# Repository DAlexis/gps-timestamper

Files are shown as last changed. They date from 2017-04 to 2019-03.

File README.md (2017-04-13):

GPS timestamper project
=======================

Open-source device based on STM32 that provides precision time stamps
of trigger signal connected to input. It use GPS PPS signal to provide
~1uS precision time mesurment. Also it makes self-calibration by PPS
every second.

Device may be used to synchronize any signals and data streams without
wired or wireless connection i.e. in geophysical researches, lightning 
detection networks, seismology and others

Currently project in protortype state and under development. Primary
function (precision timestamping) works correctly.

# Build
To build firmware you may have installed `arm-gcc` toolchain on your
linux system. If you do not need unit tests, simply comment out
corresponding line in root CMakeLists.txt (to build tests `gtest` should
be installed on your system)

Run `build.sh` and thats all. To flash MCU, connect ST-Link device to
PC and then run `flash.sh`.

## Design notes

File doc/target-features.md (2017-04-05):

Планируемый функционал прибора
=====

# Основные функции
- Много входных каналов, исключающих одновременную работу. 
(Может возникнуть трудность при неодновременном переключении)
- ЦАП устанавливает потог срабатывания
- Выход PPS
- Передача времени после каждого PPS в компьютер (можно сделать опционально через один из каналов)
- Интерфейс для тэга следующего события. Два режима - вход и выход. Выход
непрерывно повторяет тэг, вход его принимает и устанавливает взамен случайно сгенерированного
Установка тэга может быть по USB. Сгенерированные и внешние тэги различаются специальным битом

# Дополнительные функции
- Светодиод и опционально - зуммер при наличии синхросигнала, управляемый программно
(не напрямую от сигнала)

# Способы тестирования
- Соединить выход PPS со входом канала. Должно быть ровное время.
- Подаваить импульсы от стабильного генератора

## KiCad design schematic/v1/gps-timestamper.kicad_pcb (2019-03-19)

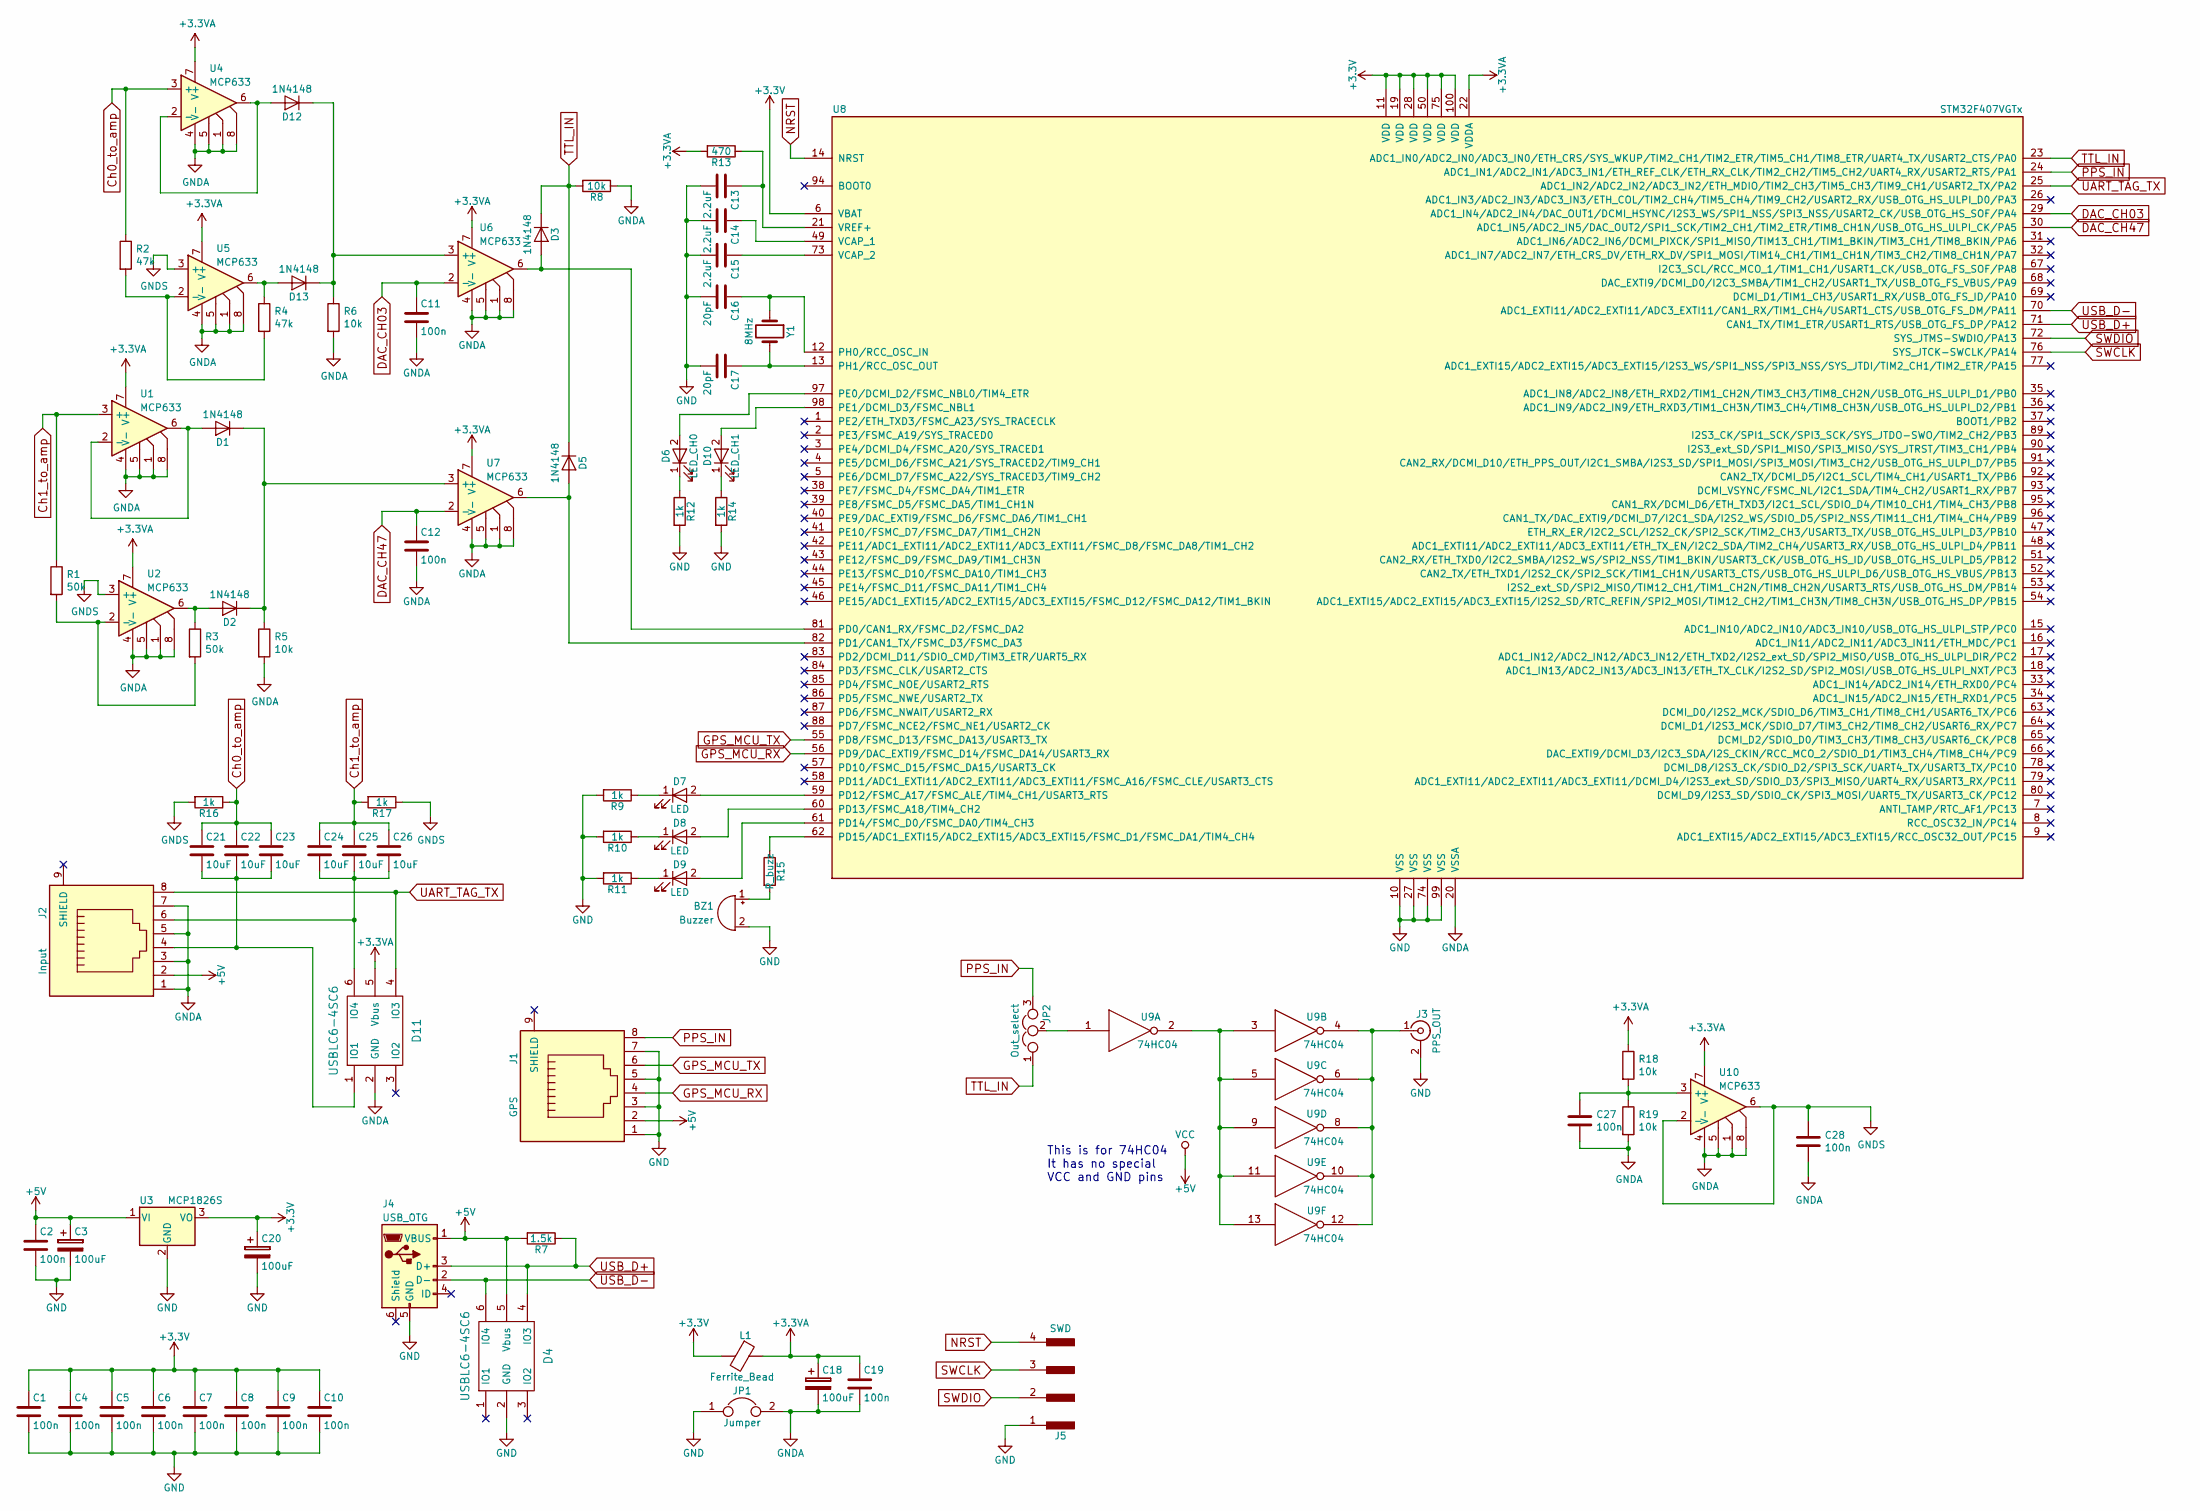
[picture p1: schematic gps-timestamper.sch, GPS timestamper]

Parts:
BZ1: Buzzer; Buzzer_12x9.5RM7.6
C1, C2, C4, C5, C6, C7, C8, C9, C10, C11, C12, C19, C27, C28: 100n; C_0805
C3, C18, C20: 100uF; CP_Tantalum_Case-B_EIA-3528-21_Wave
C13, C14, C15: 2.2uF; C_0805
C16, C17: 20pF; C_0805
C21, C22, C23, C24, C25, C26: 10uF; C_0805
D1, D2, D3, D5, D12, D13: 1N4148; D_SOD-323
D4, D11: USBLC6-4SC6; SOT-23-6
D6: LED_CH0; LED_0805
D7, D8, D9: LED; LED_0805
D10: LED_CH1; LED_0805
J1: GPS; RJ45_8
J2: Input; RJ45_8
J3: PPS_OUT; SMA_THT_Jack_Straight
J4: USB_OTG; USB_Micro-B
J5: SWD; Pin_Header_Straight_1x04_Pitch2.54mm
JP1: Jumper; GS2
JP2: Out_select; Pin_Header_Straight_1x03_Pitch2.54mm
L1: Ferrite_Bead; R_0805
R1, R3: 50k; R_0805
R2, R4: 47k; R_0805
R5, R6, R8, R18, R19: 10k; R_0805
R7: 1.5k; R_0805
R9, R10, R11, R12, R14, R16, R17: 1k; R_0805
R13: 470; R_0805
R15: R_buzz; R_0805
U1, U2, U4, U5, U6, U7, U10: MCP633; SOIC-8-N
U3: MCP1826S; SOT-223-3_TabPin2
U8: STM32F407VGTx; LQFP-100_14x14mm_Pitch0.5mm
U9: 74HC04; SOIC-14_N
Y1: 8MHz; Crystal_HC49-U_Vertical

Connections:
+3.3VA: C18.1, C19.1, D11.5 (Vbus), L1.1, R13.2, R18.1, U1.7 (V+), U2.7 (V+), U4.7 (V+), U5.7 (V+), U6.7 (V+), U7.7 (V+), U8.22 (VDDA), U10.7 (V+)
+3V3: C1.1, C4.1, C5.1, C6.1, C7.1, C8.1, C9.1, C10.1, C20.1, L1.2, U3.3 (VO), U8.6 (VBAT), U8.11 (VDD), U8.19 (VDD), U8.28 (VDD), U8.50 (VDD), U8.75 (VDD), U8.100 (VDD)
+5V: C2.1, C3.1, D4.5 (Vbus), J1.2, J2.2, J4.1 (VBUS), R7.2, U3.1 (VI), U9.14 (VCC)
Ch0_to_amp: C21.1, C22.1, C23.1, R2.1, R16.1, U4.3 (+)
Ch1_to_amp: C24.1, C25.1, C26.1, R1.1, R17.2, U1.3 (+)
DAC_CH03: C11.1, U6.2 (-), U8.29 (ADC1_IN4/ADC2_IN4/DAC_OUT1/DCMI_HSYNC/I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)
DAC_CH47: C12.1, U7.2 (-), U8.30 (ADC1_IN5/ADC2_IN5/DAC_OUT2/SPI1_SCK/TIM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)
GND: BZ1.2 (+), C1.2, C2.2, C3.2, C4.2, C5.2, C6.2, C7.2, C8.2, C9.2, C10.2, C13.2, C14.2, C15.2, C16.2, C17.2, C20.2, D4.2 (GND), J1.1, J1.3, J1.5, J1.7, J3.2 (Ext), J4.5 (GND), J5.1, JP1.1, R9.2, R10.2, R11.2, R12.2, R14.2, U3.2 (GND), U8.10 (VSS), U8.27 (VSS), U8.74 (VSS), U8.99 (VSS), U9.7 (GND)
GNDA: C11.2, C12.2, C18.2, C19.2, C27.2, C28.2, D11.2 (GND), J2.1, J2.3, J2.5, J2.7, JP1.2, R5.2, R6.2, R8.1, R19.2, U1.1, U1.4 (V-), U1.5, U1.8, U2.1, U2.4 (V-), U2.5, U2.8, U4.1, U4.4 (V-), U4.5, U4.8, U5.1, U5.4 (V-), U5.5, U5.8, U6.1, U6.4 (V-), U6.5, U6.8, U7.1, U7.4 (V-), U7.5, U7.8, U8.20 (VSSA), U10.1, U10.4 (V-), U10.5, U10.8
GNDS: C28.1, R16.2, R17.1, U2.3 (+), U5.3 (+), U10.2 (-), U10.6
GPS_MCU_RX: J1.4, U8.56 (PD9/DAC_EXTI9/FSMC_D14/FSMC_DA14/USART3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)
GPS_MCU_TX: J1.6, U8.55 (PD8/FSMC_D13/FSMC_DA13/USART3_TX)
NRST: J5.4, U8.14 (NRST)
unnamed: BZ1.1 (-), R15.2
unnamed: C13.1, R13.1, U8.21 (VREF+)
unnamed: C14.1, U8.49 (VCAP_1)
unnamed: C15.1, U8.73 (VCAP_2)
unnamed: C16.1, U8.12 (PH0/RCC_OSC_IN), Y1.1
unnamed: C17.1, U8.13 (PH1/RCC_OSC_OUT), Y1.2
unnamed: C21.2, C22.2, C23.2, D11.1 (IO1), J2.4
unnamed: C24.2, C25.2, C26.2, D11.6 (IO4), J2.6
unnamed: C27.1, R18.2, R19.1, U10.3 (+)
unnamed: D1.1 (K), D2.1 (K), R5.1, U7.3 (+)
unnamed: D1.2 (A), U1.2 (-), U1.6
unnamed: D2.2 (A), R3.1, U2.6
unnamed: D3.2 (A), U6.6, U8.81 (PD0/CAN1_RX/FSMC_D2/FSMC_DA2)
unnamed: D5.2 (A), U7.6, U8.82 (PD1/CAN1_TX/FSMC_D3/FSMC_DA3)
unnamed: D6.1 (K), R12.1
unnamed: D6.2 (A), U8.97 (PE0/DCMI_D2/FSMC_NBL0/TIM4_ETR)
unnamed: D7.1 (K), R9.1
unnamed: D7.2 (A), U8.59 (PD12/FSMC_A17/FSMC_ALE/TIM4_CH1/USART3_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)
unnamed: D8.1 (K), R10.1
unnamed: D8.2 (A), U8.60 (PD13/FSMC_A18/TIM4_CH2)
unnamed: D9.1 (K), R11.1
unnamed: D9.2 (A), U8.61 (PD14/FSMC_D0/FSMC_DA0/TIM4_CH3)
unnamed: D10.1 (K), R14.1
unnamed: D10.2 (A), U8.98 (PE1/DCMI_D3/FSMC_NBL1)
unnamed: D12.1 (K), D13.1 (K), R6.1, U6.3 (+)
unnamed: D12.2 (A), U4.2 (-), U4.6
unnamed: D13.2 (A), R4.1, U5.6
unnamed: J3.1 (In), U9.4, U9.6, U9.8, U9.10, U9.12
unnamed: JP2.2, U9.1
unnamed: R1.2, R3.2, U2.2 (-)
unnamed: R2.2, R4.2, U5.2 (-)
unnamed: R15.1, U8.62 (PD15/ADC1_EXTI15/ADC2_EXTI15/ADC3_EXTI1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)
unnamed: U9.2, U9.3, U9.5, U9.9, U9.11, U9.13
PPS_IN: J1.8, JP2.3, U8.24 (ADC1_IN1/ADC2_IN1/ADC3_IN1/ETH_REF_CLK/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)
SWCLK: J5.3, U8.76 (SYS_JTCK-SWCLK/PA14)
SWDIO: J5.2, U8.72 (SYS_JTMS-SWDIO/PA13)
TTL_IN: D3.1 (K), D5.1 (K), JP2.1, R8.2, U8.23 (ADC1_IN0/ADC2_IN0/ADC3_IN0/ETH_CRS/SYS_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)
UART_TAG_TX: D11.4 (IO3), J2.8, U8.25 (ADC1_IN2/ADC2_IN2/ADC3_IN2/ETH_MDIO/TIM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)
USB_D+: D4.4 (IO3), J4.3 (D+), R7.1, U8.71 (CAN1_TX/TIM1_ETR/USART1_RTS/USB_OTG_FS_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)
USB_D-: D4.6 (IO4), J4.2 (D-), U8.70 (ADC1_EXTI11/ADC2_EXTI11/ADC3_EXTI11/CAN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)

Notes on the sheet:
This is for 74HC04 It has no special VCC and GND pins

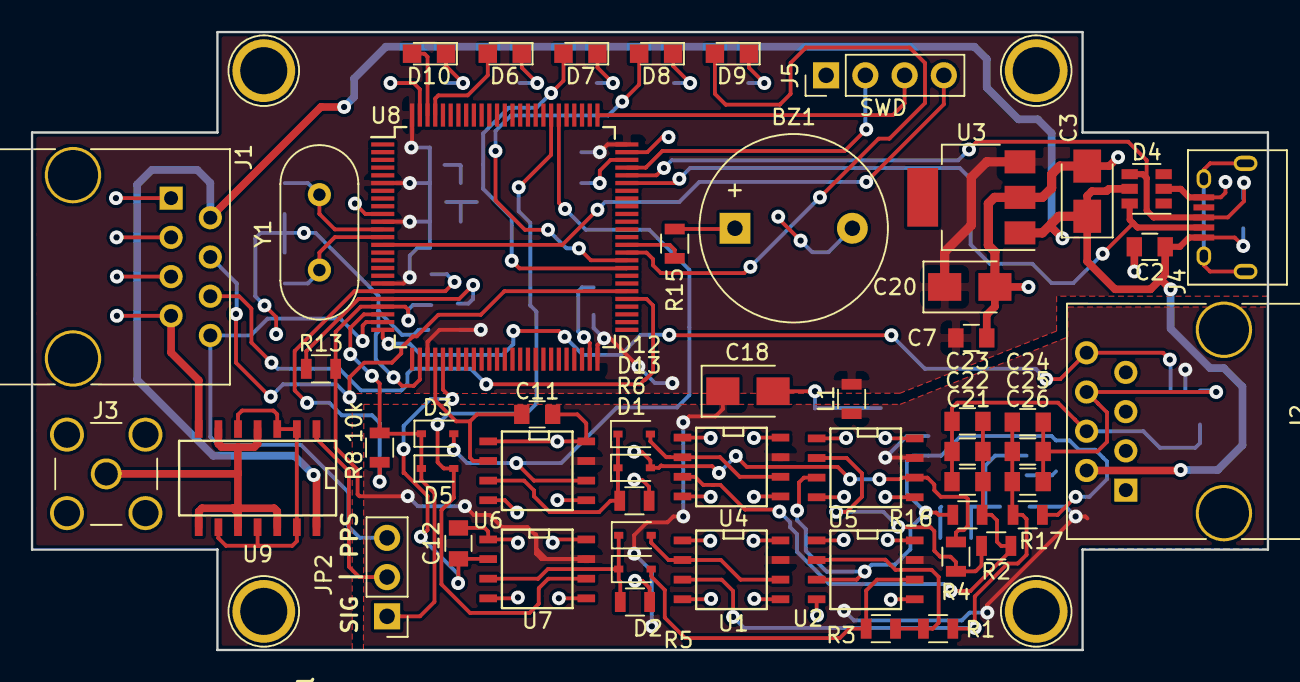
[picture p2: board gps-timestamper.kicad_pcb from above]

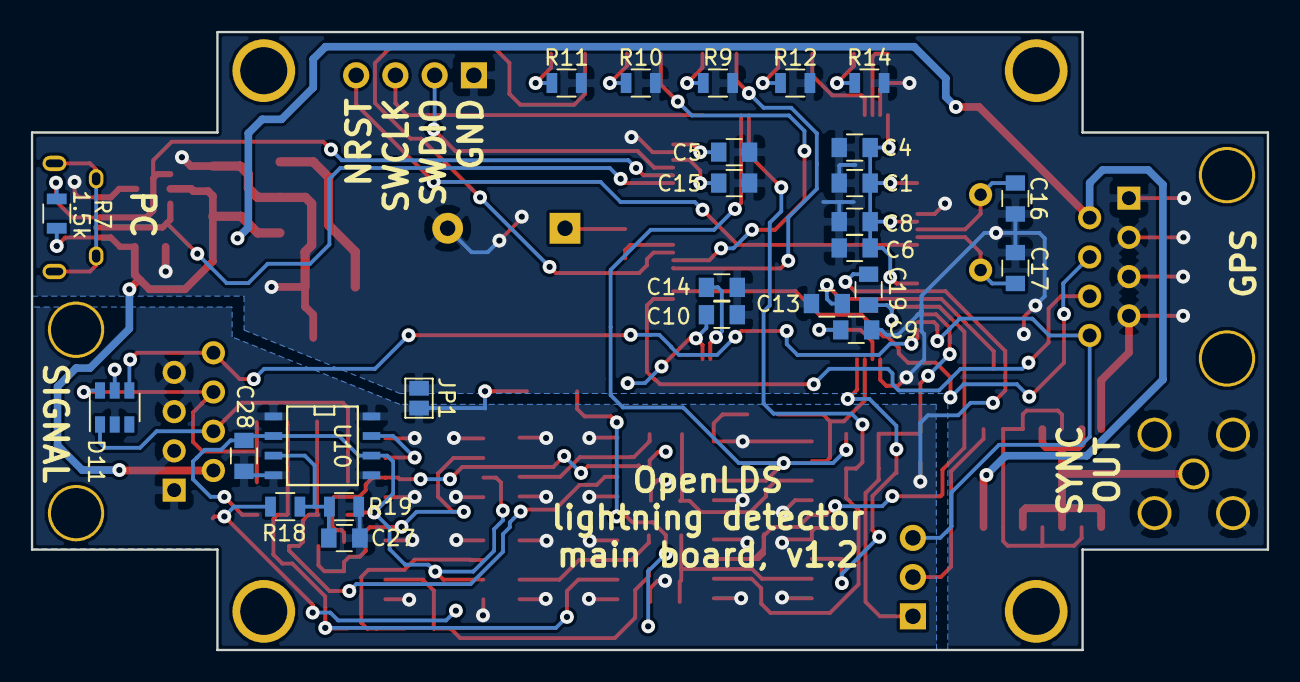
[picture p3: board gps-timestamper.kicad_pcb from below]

Board: 2 copper layers, 80.0 x 40.0 mm, 80 parts (26 on the bottom side), 53 nets.

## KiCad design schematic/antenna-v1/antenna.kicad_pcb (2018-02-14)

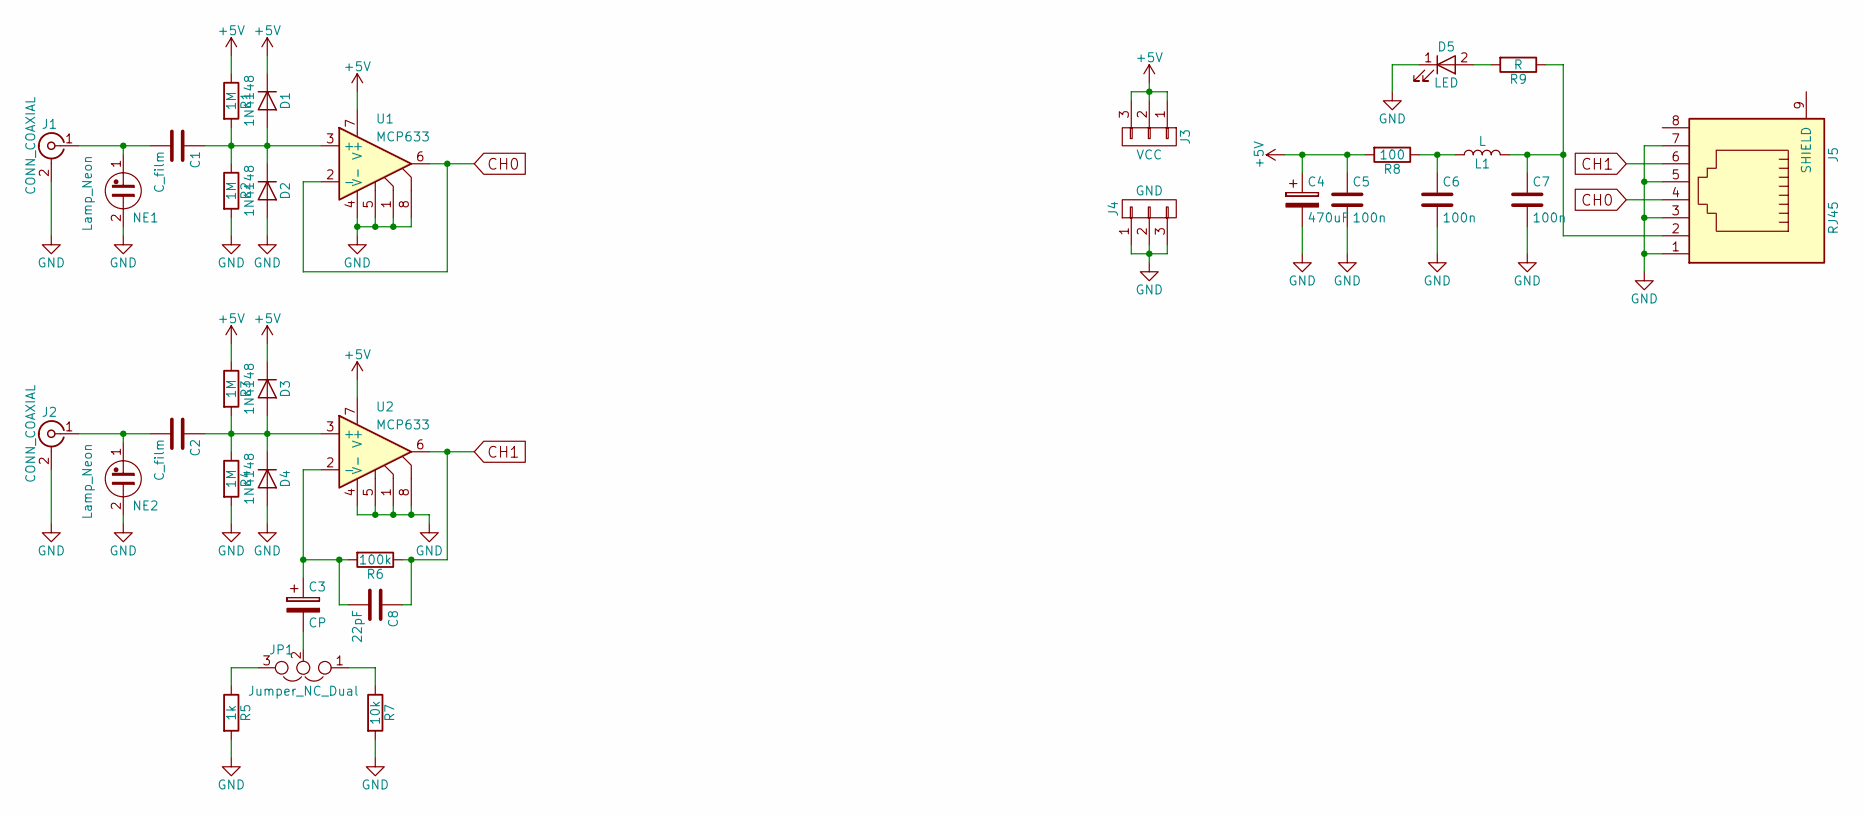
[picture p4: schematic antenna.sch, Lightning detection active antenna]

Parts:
C1, C2: C_film; C_Disc_D7.5mm_W5.0mm_P7.50mm
C3: CP; CP_Tantalum_Case-B_EIA-3528-21_Wave
C4: 470uF; CP_Tantalum_Case-D_EIA-7343-31_Wave
C5, C6, C7: 100n; C_0805
C8: 22pF; C_0805
D1, D2, D3, D4: 1N4148; D_SOD-323
D5: LED; LED_0805
J1, J2: CONN_COAXIAL; SMA_THT_Jack_Straight
J3: VCC; Pin_Header_Straight_1x03_Pitch2.54mm
J4: GND; Pin_Header_Straight_1x03_Pitch2.54mm
J5: RJ45; RJ45_8
JP1: Jumper_NC_Dual; Pin_Header_Straight_1x03_Pitch2.54mm
L1: L; R_0805
NE1, NE2: Lamp_Neon; C_Disc_D9.0mm_W5.0mm_P5.00mm
R1, R2, R3, R4: 1M; R_0805
R5: 1k; R_0805
R6: 100k; R_0805
R7: 10k; R_0805
R8: 100; R_0805
R9: R; R_0805
U1, U2: MCP633; SOIC-8_3.9x4.9mm_Pitch1.27mm

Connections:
+5V: C4.1, C5.1, D1.1 (K), D3.1 (K), J3.1, J3.2, J3.3, R1.1, R3.1, R8.2, U1.7 (V+), U2.7 (V+)
CH0: J5.4, U1.2 (-), U1.6
CH1: C8.1, J5.6, R6.1, U2.6
GND: C4.2, C5.2, C6.2, C7.2, D2.2 (A), D4.2 (A), D5.1 (K), J1.2 (Ext), J2.2 (Ext), J4.1, J4.2, J4.3, J5.1, J5.3, J5.5, J5.7, NE1.2, NE2.2, R2.2, R4.2, R5.2, R7.2, U1.1, U1.4 (V-), U1.5, U1.8, U2.1, U2.4 (V-), U2.5, U2.8
unnamed: C1.1, D1.2 (A), D2.1 (K), R1.2, R2.1, U1.3 (+)
unnamed: C1.2, J1.1 (In), NE1.1
unnamed: C2.1, D3.2 (A), D4.1 (K), R3.2, R4.1, U2.3 (+)
unnamed: C2.2, J2.1 (In), NE2.1
unnamed: C3.1, C8.2, R6.2, U2.2 (-)
unnamed: C3.2, JP1.2
unnamed: C6.1, L1.1, R8.1
unnamed: C7.1, J5.2, L1.2, R9.1
unnamed: D5.2 (A), R9.2
unnamed: JP1.1, R7.1
unnamed: JP1.3, R5.1

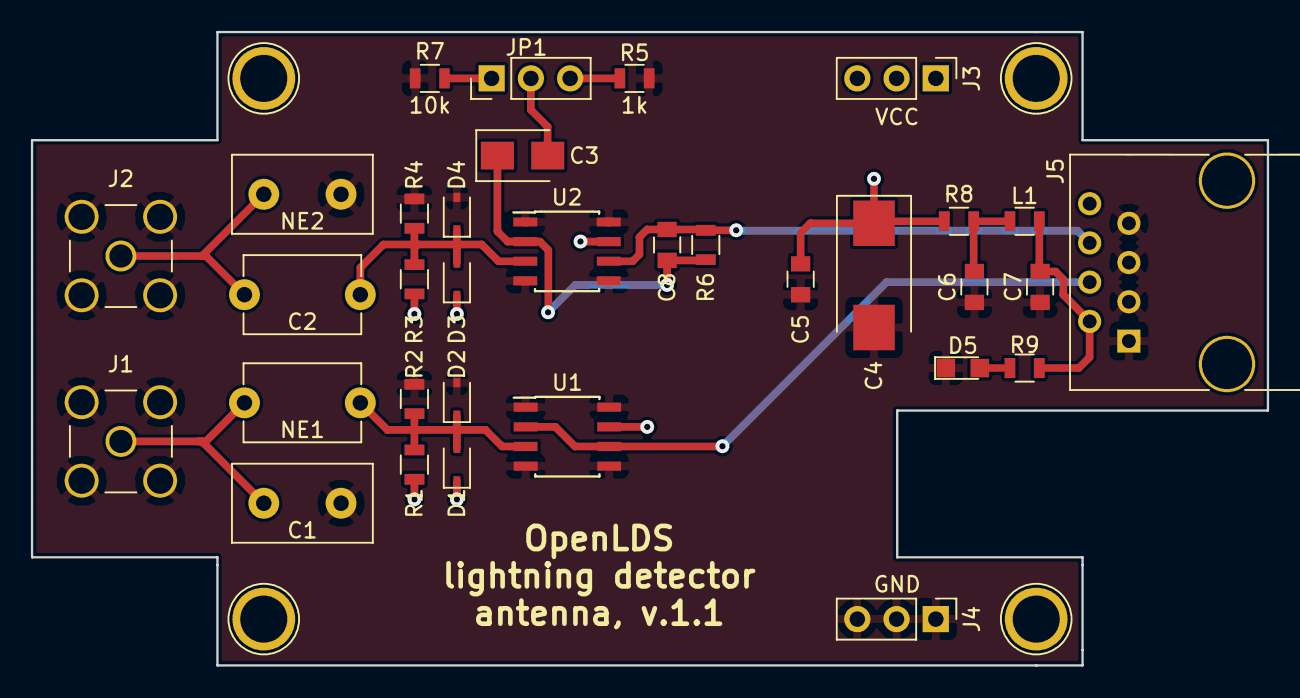
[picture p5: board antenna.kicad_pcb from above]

Board: 2 copper layers, 80.0 x 41.0 mm, 33 parts (0 on the bottom side), 15 nets.

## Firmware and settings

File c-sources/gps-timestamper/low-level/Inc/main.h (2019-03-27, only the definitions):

#define Signal_Pin GPIO_PIN_0
#define Signal_GPIO_Port GPIOA
#define PPS_Pin GPIO_PIN_1
#define PPS_GPIO_Port GPIOA
#define TAG_USART2_TX_Pin GPIO_PIN_2
#define TAG_USART2_TX_GPIO_Port GPIOA
#define TAG_USART2_RX_Pin GPIO_PIN_3
#define TAG_USART2_RX_GPIO_Port GPIOA
#define DAC_treshold_03_Pin GPIO_PIN_4
#define DAC_treshold_03_GPIO_Port GPIOA
#define DAC_treshold_47_Pin GPIO_PIN_5
#define DAC_treshold_47_GPIO_Port GPIOA
#define LED_ch7_Pin GPIO_PIN_7
#define LED_ch7_GPIO_Port GPIOE
#define LED_2_Pin GPIO_PIN_12
#define LED_2_GPIO_Port GPIOD
#define LED_3_Pin GPIO_PIN_13
#define LED_3_GPIO_Port GPIOD
#define LED_4_Pin GPIO_PIN_14
#define LED_4_GPIO_Port GPIOD
#define Sound_pin_Pin GPIO_PIN_15
#define Sound_pin_GPIO_Port GPIOD
#define JSON_OUTPUT_USART1_TX_Pin GPIO_PIN_9
#define JSON_OUTPUT_USART1_TX_GPIO_Port GPIOA
#define JSON_OUTPUT_USART1_RX_Pin GPIO_PIN_10
#define JSON_OUTPUT_USART1_RX_GPIO_Port GPIOA
#define Sig_ch0_Pin GPIO_PIN_0
#define Sig_ch0_GPIO_Port GPIOD
#define Sig_ch1_Pin GPIO_PIN_1
#define Sig_ch1_GPIO_Port GPIOD
#define Sig_ch2_Pin GPIO_PIN_2
#define Sig_ch2_GPIO_Port GPIOD
#define SIg_ch3_Pin GPIO_PIN_3
#define SIg_ch3_GPIO_Port GPIOD
#define Sig_ch4_Pin GPIO_PIN_4
#define Sig_ch4_GPIO_Port GPIOD
#define Sig_ch5_Pin GPIO_PIN_5
#define Sig_ch5_GPIO_Port GPIOD
#define Sig_ch6_Pin GPIO_PIN_6
#define Sig_ch6_GPIO_Port GPIOD
#define Sig_ch7_Pin GPIO_PIN_7
#define Sig_ch7_GPIO_Port GPIOD
#define LED_0_Pin GPIO_PIN_0
#define LED_0_GPIO_Port GPIOE
#define LED_1_Pin GPIO_PIN_1
#define LED_1_GPIO_Port GPIOE

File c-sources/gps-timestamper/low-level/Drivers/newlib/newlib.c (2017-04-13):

#include <errno.h>
#include <sys/stat.h>
#include <sys/times.h>
#include <sys/unistd.h>
#include <sys/time.h>
#include <usbd_cdc_if.h>

#if defined STM32F1
# include <stm32f1xx_hal.h>
#elif defined STM32F2
# include <stm32f2xx_hal.h>
#elif defined STM32F4
# include <stm32f4xx_hal.h>
#endif

#include "cmsis_os.h"

#define USB_WRITE_MIN_DELAY   1

//extern uint32_t __get_MSP(void);

#ifdef USE_UART_DEBUG_OUTPUT
    extern UART_HandleTypeDef huart1;
#endif
//extern uint64_t virtualTimer;

#undef errno
extern int errno;


char *__env[1] = { 0 };
char **environ = __env;

int _write(int file, char *ptr, int len);

void _exit(int status)
{
    while (1);
}

int _close(int file)
{
    return -1;
}

int _execve(char *name, char **argv, char **env)
{
    errno = ENOMEM;
    return -1;
}

int _fork()
{
    errno = EAGAIN;
    return -1;
}

int _fstat(int file, struct stat *st)
{
    st->st_mode = S_IFCHR;
    return 0;
}

int _getpid()
{
    return 1;
}
/*
int _gettimeofday(struct timeval *tv, struct timezone *tz)
{
    tv->tv_sec = virtualTimer / 1000;
    tv->tv_usec = (virtualTimer % 1000) * 1000;
    return 0;
}*/

int _isatty(int file)
{
    switch (file)
    {
    case STDOUT_FILENO:
    case STDERR_FILENO:
    case STDIN_FILENO:
        return 1;
    default:
        //errno = ENOTTY;
        errno = EBADF;
        return 0;
    }
}

int _kill(int pid, int sig)
{
    errno = EINVAL;
    return (-1);
}

int _link(char *old, char *new)
{
    errno = EMLINK;
    return -1;
}

int _lseek(int file, int ptr, int dir)
{
    return 0;
}

caddr_t _sbrk(int incr)
{
	extern char __bss_end__;
	extern char _estack;
	char* heapLimit = &_estack - 0x200;

    //extern char isMemoryCorrupted;

    static char* current_heap_end;
    char* current_block_address;

    if (current_heap_end == 0)
    {
      current_heap_end = &__bss_end__;
    }

    current_block_address = current_heap_end;

    // Need to align heap to word boundary, else will get
    // hard faults on Cortex-M0. So we assume that heap starts on
    // word boundary, hence make sure we always add a multiple of
    // 4 to it.
    incr = (incr + 3) & (~3); // align value to 4
    if (current_heap_end + incr > heapLimit)
    {
      // Some of the libstdc++-v3 tests rely upon detecting
      // out of memory errors, so do not abort here.
    #if 0
      extern void abort (void);
      _write (1, "_sbrk: Heap and stack collision\n", 32);
      abort ();
    #else
      // Heap has overflowed
      //isMemoryCorrupted = 1;

      errno = ENOMEM;
      return (caddr_t) - 1;
    #endif
    }

    current_heap_end += incr;

    return (caddr_t) current_block_address;
}

int _read(int file, char *ptr, int len)
{
    switch (file)
    {
    case STDIN_FILENO:
    	//CDC_Receive_FS(ptr, len);
        //HAL_UART_Receive(&UART_Handle, (uint8_t *)ptr, 1, HAL_MAX_DELAY);
        //return 1;
    default:
        errno = EBADF;
        return -1;
    }
}

int _stat(const char *filepath, struct stat *st)
{
    st->st_mode = S_IFCHR;
    return 0;
}

clock_t _times(struct tms *buf)
{
    return -1;
}

int _unlink(char *name)
{
    errno = ENOENT;
    return -1;
}

int _wait(int *status)
{
    errno = ECHILD;
    return -1;
}

int _write(int file, char *ptr, int len)
{
	static xSemaphoreHandle mutex = NULL;
	if (!mutex)
		mutex = xSemaphoreCreateMutex();
	static uint32_t lastTime = 0;
	uint32_t time = HAL_GetTick();
    switch (file)
    {
    case STDOUT_FILENO: // stdout
    case STDERR_FILENO: // stderr
    	xSemaphoreTake(mutex, portMAX_DELAY);
    	if (time - lastTime < USB_WRITE_MIN_DELAY)
    		HAL_Delay(USB_WRITE_MIN_DELAY);
    	CDC_Transmit_FS(ptr, len);
    	lastTime =  HAL_GetTick();
    	xSemaphoreGive(mutex);
        break;
    default:
        errno = EBADF;

        return -1;
    }
    return len;
}

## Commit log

2016-11-30 [firmware] Led blink stub. Builds with CMake, not tested
2016-12-01 [firmware] Led blinks works
2016-12-06 [firmware] NMEA receiver and parser added; unit test on PC added; directories structure improved; USB debug messages delay added (to prevent losed messages)
    [gps-timestamper.ioc]
2016-12-09 [firmware] Device protorype works. Invalid round time when gps misses GPGPA over uart
2017-04-05 Schematic and doc initial
    [gps-timestamper.kicad_pcb, gps-timestamper.sch]
2017-04-13 Fixes: queue use correct size(), queue overflow message, all messages changed to JSON format
    [nmea-receiver.cpp]
2017-04-13 Updated stm32 copyrights in generated files
2017-04-13 [PCB] [firmware] Schematics added, GPIO labels added, DAC generated code added
    [gps-timestamper.sch]
2017-04-18 [PCB] [firmware] PCB: version 1 schematic seems normal, firmware: last second period output added
    [gps-timestamper.kicad_pcb, gps-timestamper.sch]
2017-04-19 [PCB] pcb seems done, silkscreen sims accurate
    [gps-timestamper.kicad_pcb, gps-timestamper.sch]
2017-04-20 [PCB] Design improved. RJ-45 input, buffered PPS output
    [gps-timestamper.kicad_pcb, gps-timestamper.sch]
2017-04-25 [PCB] Active antenna schmatics
    [antenna.kicad_pcb, antenna.sch, gps-timestamper.sch]
2017-04-28 [PCB] Antenna done and input trigger output added for main device
    [antenna.sch, gps-timestamper.kicad_pcb, gps-timestamper.sch]
2018-01-12 Fix for PCBs: op amps
    [antenna.kicad_pcb, gps-timestamper.kicad_pcb, gps-timestamper.sch]
2018-02-14 v1.1 PCB group done
    [antenna.kicad_pcb, antenna.sch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]
2018-11-22 GTest external dependency removed, main module schematic upgraded to latest kicad version
    [gps-timestamper.sch]
2019-03-19 New fixed schematics
    [gps-timestamper.kicad_pcb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]
2019-03-27 Threshold voltage controller, leds, some refactoring

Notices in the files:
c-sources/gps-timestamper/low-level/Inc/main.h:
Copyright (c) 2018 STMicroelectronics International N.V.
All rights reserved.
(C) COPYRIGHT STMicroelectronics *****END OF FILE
